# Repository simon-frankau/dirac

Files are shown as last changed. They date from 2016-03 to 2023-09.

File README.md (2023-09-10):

Dirac: The simplest single-board computer I can face building
=============================================================

Dirac is a simple single-board Z80-based retrocomputer. It's the
simplest one I can face building. I wanted to produce something that's
a bit nicer than a pure minimal computer, so it has:

 * Serial I/O
 * A counter/timer to provide the clock for serial I/O and also allow
   regular timer interrupts
 * Mass storage via SD card
 * Banked RAM

The banked RAM is a bit excessive, but it always seemed a bit magical
when I was small, and a 64KB address space is less than I really
like.

What's the aim?
---------------

The aim is to get CP/M running, with associated programs, with a
probably intermediate step of BASIC. The design is intended to be
retro where convenient. So, it has separate DIP chips for Z80, RAM,
EEPROM, CTC, SIO, and 74-series logic for the glue. I don't use a CPLD
let alone an FPGA or high-power modern microcontroller to cheat.

However, the non-volatile storage is EEPROM rather than EPROM, and I'm
just using a great big SRAM, rather than bothering with the pain of
DRAM. Serial I/O uses a proper Z80 SIO, but one ports connects to a
TTL serial to USB dongle, rather than RS-232 proper (the second port
does real RS232). After a false start, I use an oscillator package,
rather than a raw crystal. Mass storage is an SD card, via a break-out
board. I see little reason to cause myself a lot of pain of using a
more difficult and less available form of storage!

(Having said that, recreating old-school floppy drive control sounds
like a fun project in itself...)

Why's it called Dirac?
----------------------

Projects need names. "Z80-based single board computer" just isn't a
snappy name, and doesn't distinguishing it from any other.

I grew up on a ZX Spectrum. It had colour graphics. This machine has
no graphics at all. It has serial I/O, and that's basically
it. Instead of a spectrum of I/O, it's got a Dirac delta function.

(Random fact: Dirac was a fellow of my old College, and his gown still
hangs in the Master's Lodge. I believe it's chained in place, pesky
undergrads.)

Why's it taken so long?
-----------------------

(I bought my first pile of components in early 2010.)

Children. They're lovely, but they don't mix well with soldering irons!

What's here?
------------

* **[schematics](./schematics/README.md)** covers the hardware
* **[src](./src)** contains the assembly source to program it with
* **[tools](./tools)** contains the tools to do the required
    translations to make workable images

What's the current state?
-------------------------

I tried creating a simple loader. It allows you to encode your
binaries as hex, load them and execute them. With a recent fix, this
is now working reasonably reliably. I can plug the thing in to USB,
it'll power itself from the USB port, and I can talk to the monitor at
4800 8-N-1.

I have code to use the SD card interface in read-only mode, and have a
basic CP/M port running.

It will run Infocom's Hitchhiker's Guide To The Galaxy.

Where did the CP/M parts come from?
-----------------------------------

src/cpm22.asm is a lightly-modified copy of CPM22.Z80, extracted from
http://www.cpm.z80.de/download/cpm2-asm.zip

(I had disassembled a working CP/M image myself, but this comes with
comments and produces the same results so... why not?)

I previously used images/appleiicpm.dsk, which is taken from
http://schorn.ch/cpm/zip/cpm2.zip, as a relatively arbitrary
easy-to-reverse-engineer disk image. I've switched to building my own
disk images.

What do I need?
---------------

* **Kicad** for the schematics
* **zasm** (http://sourceforge.net/projects/zasm/ /
    http://k1.spdns.de/Develop/Projects/zasm/) for the assembly
* **lua** to run the tools

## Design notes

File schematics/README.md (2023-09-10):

Dirac's Hardware
================

[Schematics](./z80-schematics.pdf)

The schematics in this directory are in Kicad format. I previously
used Eagle, but it seems a good idea to support Open Source. I'm
clearly still learning it, so please forgive the worst
blunders. Feedback is appreciated.

Dirac's implemented using stripboard and a shedload of wires. You've
seen those neat stripboard projects? This is not one of
them. Super-tangled. This explains why you won't find any PCB designs.

Implementation is pretty straightforward, as I've implemented it a
feature at a time. An oscilloscope has been a life-saver, and I've
stuck pin-out labels on top of the chips, which has made working out
what's going on much easier.

Miscellaneous notes
-------------------

* NMI is basically unusable. It's not debounced, so by the time it's
  finished bouncing, the CPU's stack can be all over the place. The
  Spectrum had unusable NMI, so I feel I'm in good company. ;)

* The banking implementation is a bit funky, using as it does the
  74LS289. This is a chip obscure enough they don't even seem to have
  a CMOS version of. It's a small RAM, suitable for holding a banking
  map, but the outputs are inverting, meaning the physical address we
  think we're writing is actually the opposite of what we're really
  writing. We have to rearrange the EEPROM contents at the bank level
  when we write it. We also have to be careful with the TTL/CMOS
  levels between the chips. Fortunately, the big chips are
  TTL-tolerant, and I've used 74HCT for the others that are driven by
  the '289.

* We have a flip-flop to enable banking as the contents are in an
  unknown state at power on. All pages are mapped to bank 0 (physical
  page 0xFF) at start-up, and banking is enabled by the first write
  (and disabled on reset).

* Banking configuration can also be read back, which seemed a nice
  idea if you want to save and restore the current state, but does
  seem overkill really for such a simple design.

* Address decoding is such that you can page in RAM so that writes are
  disabled. Useful for faking ROM.

* There's a bog-standard Z80 CTC and SIO set-up. TO[01] are used to
  clock the SIO, and TO2 and TO3 are chained so that you can get a
  clock suited to a clock interrupt. The SIO output is TTL, so you can
  feed it into a USB serial adapter, or a level converter for
  traditional RS232. There are two ports, so in my implementation I
  have one of each.

* An SD card interface is implemented using the parallel ports.

Memory map
----------

The memory is divided into 4k (12-bit addressable) pages. The top
4-bits of Z80 "virtual" addresses are then mapped into "physical"
addresses in a 20-bit address space. That is, there's a 4-bit-to-8-bit
look-up.

Physical addressing is as follows:

$80000 - $9FFFF RAM, mapped read-only
$C0000 - $DFFFF RAM, mapped read-write

$00000 - $07FFF EEPROM

Yep, we only have 160KB of actual storage mapped into the 1MB address
space.

To perform virtual address mapping, so that address virtual address
$Xabc is mapped to $YZabc, you should "out" $YZ to I/O port $0X. You
can "in" from the same I/O port to get the current mapping.

Initially, banking is disabled, and all slots are mapped to $00xxx,
the bottom of the EEPROM. As soon as you write anything, banking is
enabled, and you will get random contents for the other banking slots.
So, your best bet is to initialise the bottom slot to $00xxx while
you're running code in it, and then initialise the other slots.

### Writing an EEPROM

The address lines that get passed through the banking hardware get
inverted before they actually reach the EEPROM, so you should write
your EEPROMs to cope with A12-A14 being inverted.

Parallel I/O ports and SD card
------------------------------

We have 8 bits of input and output available as a parallel port, at
$30. The bottom 3 bits of each port are used by the SD card SPI
interface:

### Out

$01 - Data
$02 - Clock
$04 - Select (active low)

### In

$01 - Data (inverted)
$02 - Card detected (active low)
$04 - Write protected (active low)

### Interface circuitry

The circuitry might look a little odd, so I'll explain. The SD card
uses 3.3V, and Dirac uses 5V, so we need some conversion. The SD card
has 100K pull-ups, and we use 10K resistors to convert, so we rather
take precedence.

In the outward direction, we need to bring the voltage down, so we use
voltage dividers. The ratio is 1:1, so the voltage is split in half.
2.5V when running off USB might seem a little low, but it should be
logic high for 3.3V logic, and won't go too high if Dirac is run off
e.g. 4x 1.5V AA batteries (giving 3V out, after division).

On the incoming direction, we just provide 5V pull-ups for card
detection and write protection lines (those being implemented as
switches pulling to ground on the SD card socket). The actual data
line is handled differently. 2.5V is TTL high, but not 5V CMOS high.
The input buffer is not HCT (I didn't look far enough ahead in Dirac's
design for that), but the inverter is. So, we pass it through the
inverter to buffer the level. Sadly this inverts the data line, but
that's easy enough to fix in software.

I/O map
-------

The upper nybble of the I/O port number denotes the I/O subsytem, the
lower nybble for addresses within the subsystem. The ports are:

$0X - Banking (see description above)
$1X - CTC
$2X - SIO
$3X - Parallel I/O ports

(And the rest are unassigned right now.)

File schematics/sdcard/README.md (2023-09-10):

# SD card breakout board schematics

[Schematic](./sdcard.pdf)

## What's this?

These are my reverse-engineered schematics for the SD card breakout
board I'm using. Why? While I'm not exactly an expert on SD card
breakout boards, I wouldn't be surprised if they're not all identical,
and the interpretation of the main board schematics (in the directory
above) rather relies on knowing how the breakout board is wired up and
how it connects to the actual SD card.

# So, what's the issue with the board?

While it has a 5V -> 3.3V regulator, it doesn't do any level
conversion on the signal lines, and SD cards aren't 5V tolerant. I
need to do some conversion on the Dirac side.

## And so?

I've added level conversion hardware to the main Dirac schematic to
handle this. The README.md in the directory above explains.

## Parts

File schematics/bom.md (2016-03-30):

Bill of materials
=================

NB: The part numbers on the schematic are often not *quite* right -
I'm using what's available in the parts library that is
pin-compatible. The actual choice of components is detailed below.

ICs
---

* U1 - Z84C0010PEG CMOS CPU (Z80) 10MHZ, 84C00, DIP40
* U2 - AS6C1008-55PCN SRAM, 1MB, 2.7V-5.5V, 128KX8, PDIP32
* U3 - CAT28C256BL-12 EEPROM, 256K, 32KX8, 120NS, PDIP28 (Use a ZIF socket)
* U4,5 - 2x 74LS289 16x4 inverting RAM with open collector output, DIP16
* U6 - 74HC138N 3-to-8 demux, DIP16
* U7 - 74HCT540N inverting octal buffer with tri-state outputs, DIP20
* U8 - 74HCT00N quad NAND, DIP14
* U9 - 74HCT32N quad OR, DIP14
* U10 - Z84C3006PEG CTC (Z80) 6MHZ, 84C30, DIP28
* U11 - Z84C4006PEG SIO/O (Z80) 6MHZ, 84C40, DIP40
* U12 - 74HC574E, oct D-type FF, DIP20
* U13 - 74HC541N, octal buffer with tri-state outputs, DIP20

Resistors
---------

* R1-8 - 10k resistor network
* R9-12 - 4x 10k, 0.25W 5% resistors

Capacitors
----------

* C1 - 10uF ceramic capacitor
* C2-15 - 13x 0.1uF ceramic capacitors (One per IC, plus reset-on-start)

Misc
----

* D1 - 5mm red LED
* SW1,2 - Normally-open push button
* X1 - Clock package, 2MHz
* JP1 - 2 pin 0.1" header and jumper
* P1 - 6 pin 0.1" female header

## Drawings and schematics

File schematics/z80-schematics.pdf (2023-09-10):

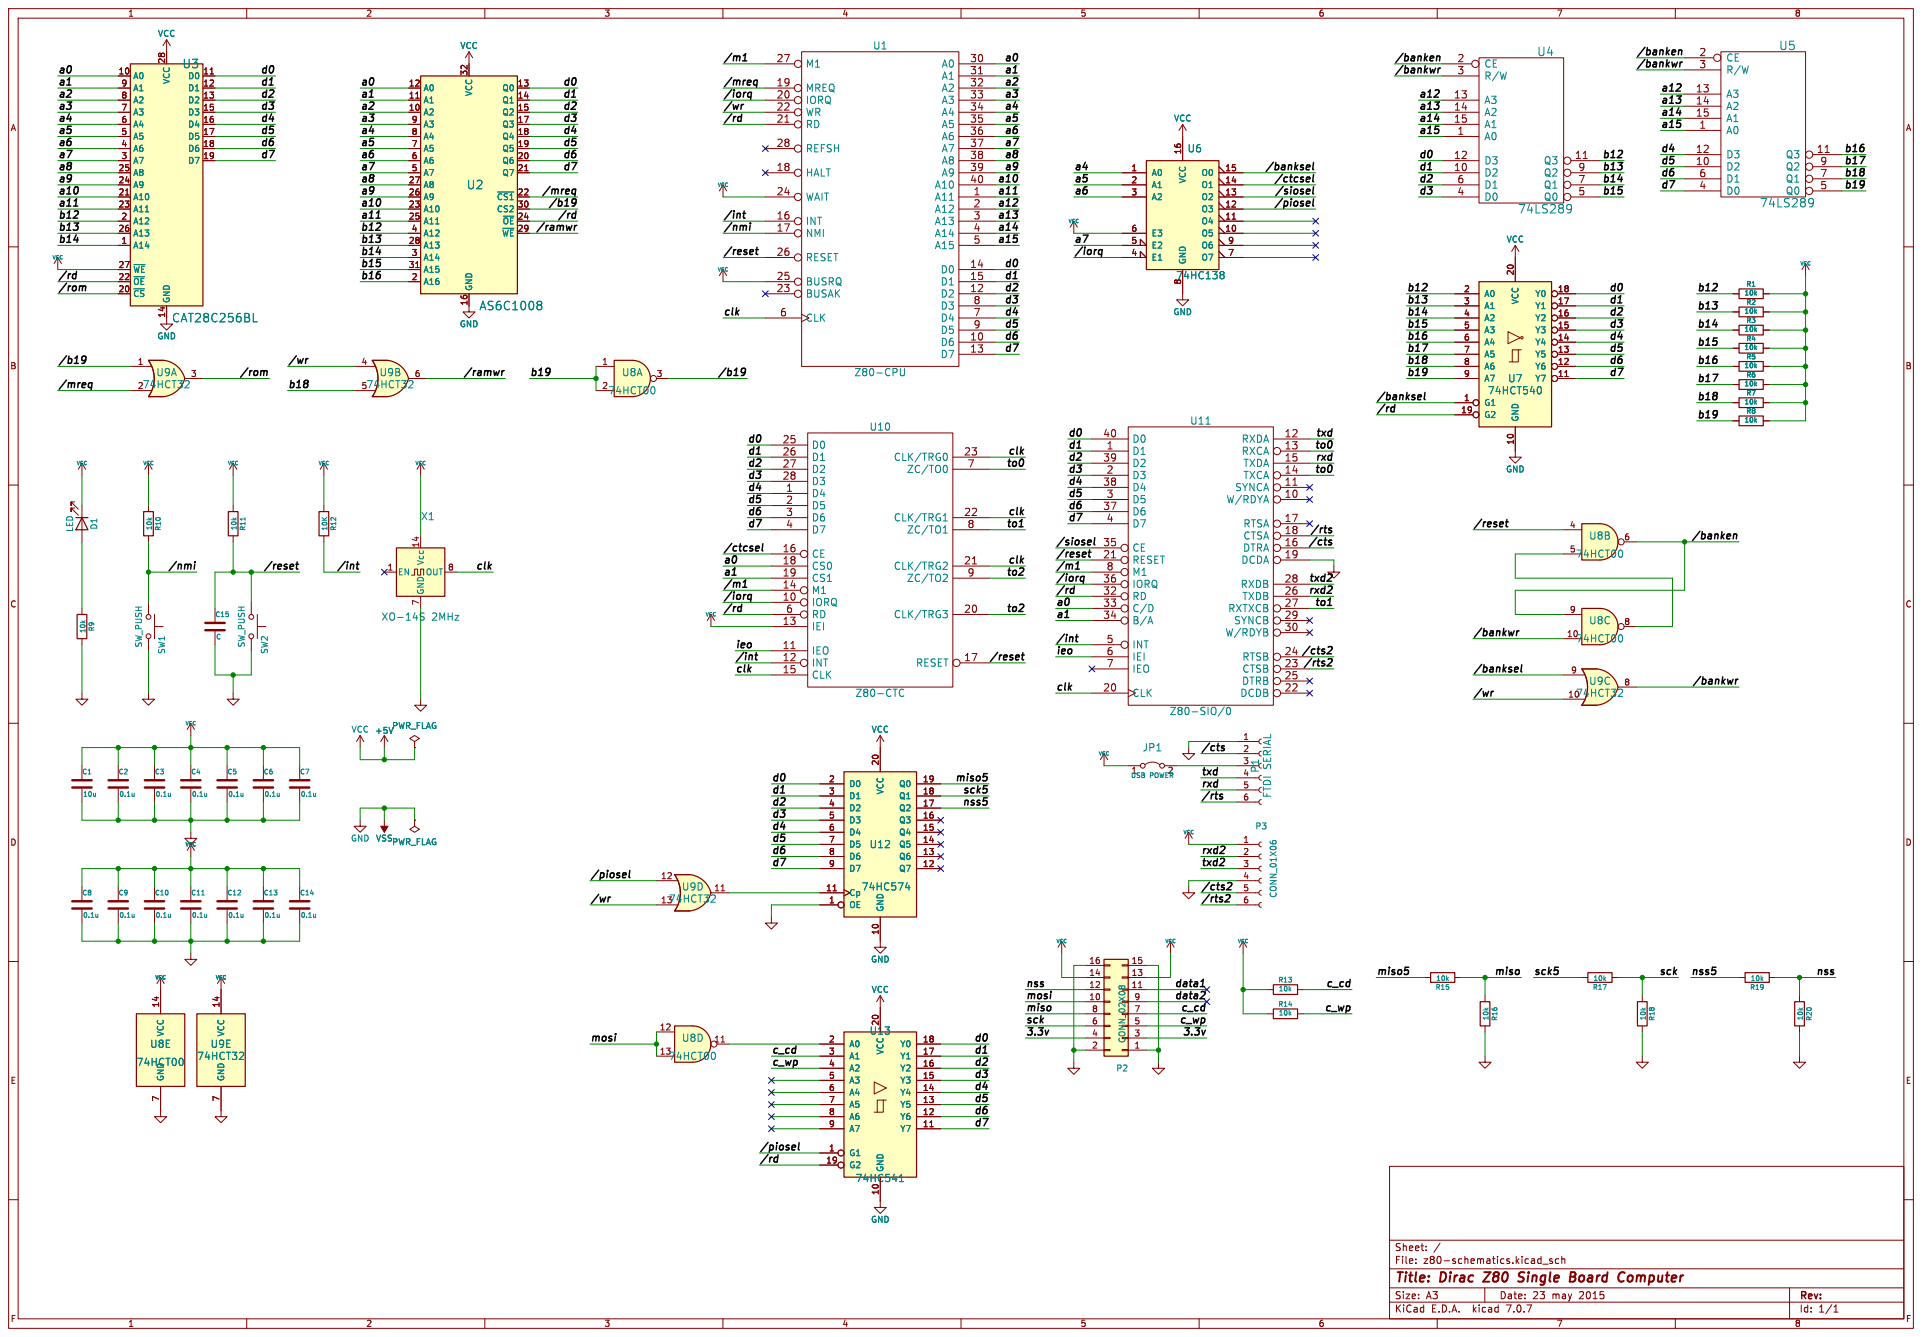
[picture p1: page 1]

Id: 1/1 Title: Dirac Z80 Single Board Computer File: z80-schematics.kicad_sch Sheet: /

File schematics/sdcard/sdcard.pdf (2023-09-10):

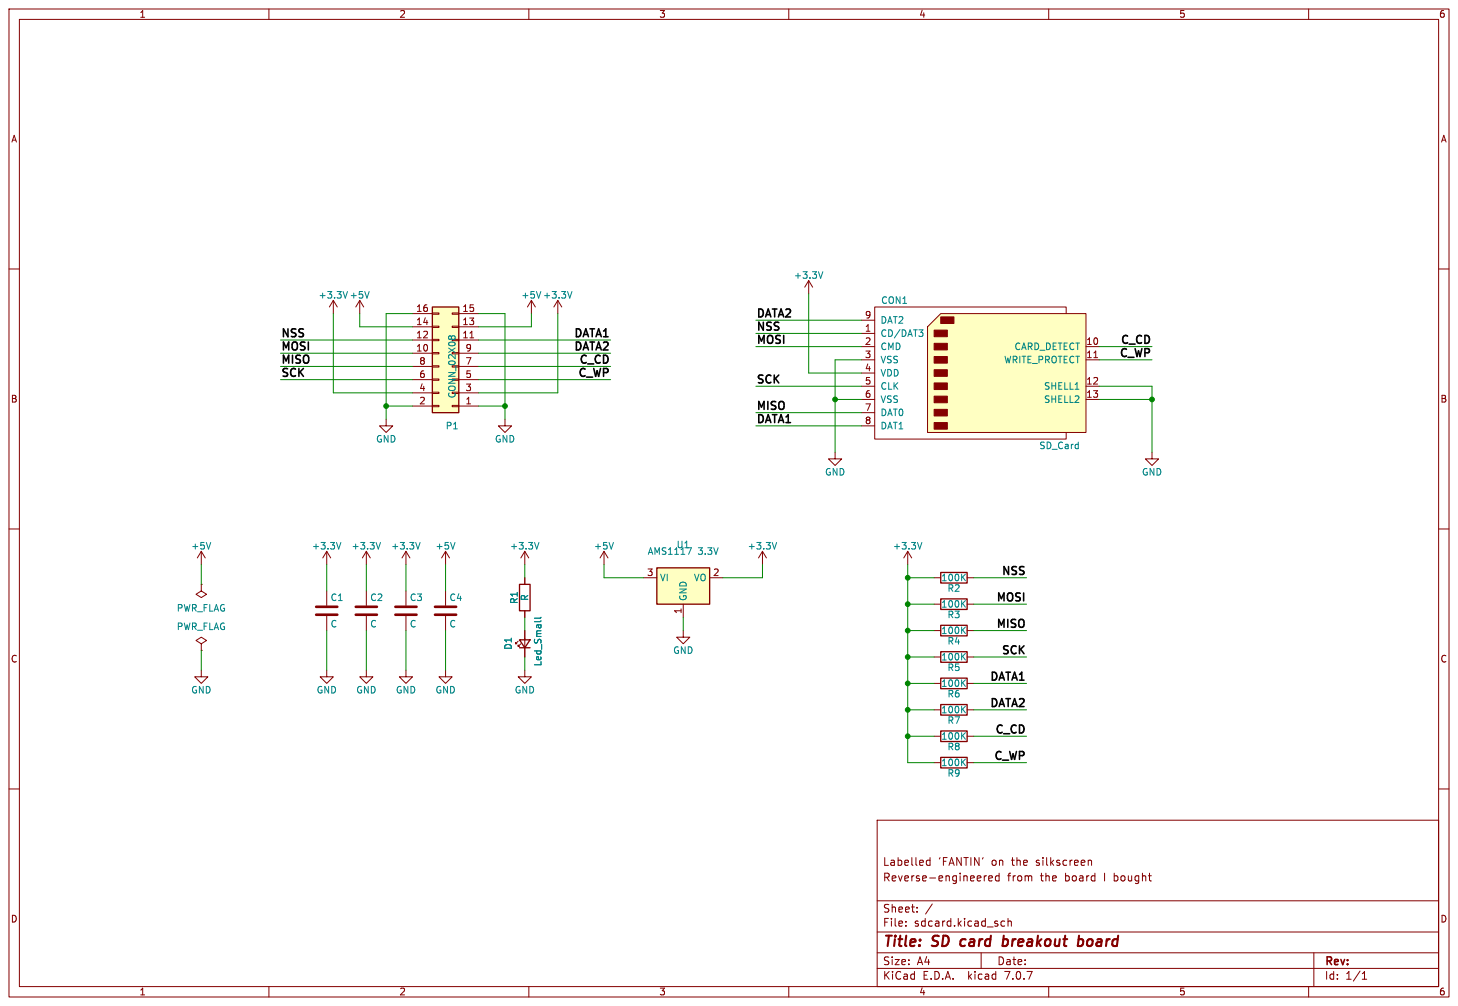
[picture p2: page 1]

1 VO 2 VI 3 U1 AMS1117 3.3V CD/DAT3 1 CARD_DETECT 10 WRITE_PROTECT 11 SHELL1 12 SHELL2 13 CMD 2 VSS 3 VDD 4 CLK 5 VSS 6 DAT0 7 DAT1 8 DAT2 9 CON1 SD_Card +5V
DATA2 C_CD

14 | 13
12 | 11

MOSI | | 10

Id: 1/1 Title: SD card breakout board

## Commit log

2013-10-06 Added a few quick comments on the slots used by the tests.
2013-11-14 Add exercising of the clock interrupt (needs debugging).
2013-11-15 Make the counter-interrupt-testing code work nicely.
2013-11-20 Prepare groundwork for testing SIO.
2013-11-23 Fix a couple of simple bugs in the SIO routines, added code to change case and echo back the character you typed. Simple non-interrupt serial I/O working.
2014-10-11 Very basic core schematic, in Kicad
    [z80-schematics.sch]
2014-10-11 Non-I/O digital logic complete - CPU, ROM, RAM, bank switching and glue
    [z80-schematics.sch]
2014-10-11 Update .gitignore with kicad file types
2014-10-11 Moving main buses over to label-based connections for improved readability
    [z80-schematics.sch]
2014-10-11 Tidied up the bank-switcher (changed to label-based connections)
    [z80-schematics.sch]
2014-10-11 Further label-ification
    [z80-schematics.sch]
2014-10-11 Finished switching to label-based connections
    [z80-schematics.sch]
2014-10-11 Added odds and ends to the schematic
    [z80-schematics.sch]
2014-10-19 Marked resistors as 10k
    [z80-schematics.sch]
2014-10-19 Added the CTC wiring
    [z80-schematics.sch]
2014-10-19 Added serial I/O
    [z80-schematics.sch]
2014-10-19 Added (incomplete) general I/O buffers.
    [z80-schematics.sch]
2014-10-19 Added decoupling caps.
    [z80-schematics.sch]
2014-10-22 Move assembly and tools into subdirectories
2015-01-06 Make case insensitive
2015-01-06 Add memory-map printing
2015-05-23 Added component identifiers to the schematic
    [z80-schematics.sch]
2015-05-23 Added initial (incomplete) bill of materials
2016-03-29 Update schematics to newer version of kicad
    [z80-schematics.sch]
2016-03-30 Label schematics with values
    [z80-schematics.sch]
2016-03-30 Add bill of materials for the schematic
2016-05-01 Fix accidental DRC failures
    [z80-schematics.sch]
2016-05-01 Fix DRC and fill in pull-ups on incomplete I/O circuitry
    [z80-schematics.sch]
2016-05-01 Add support for read-only RAM mapping
    [z80-schematics.sch]
2016-05-01 Update the README.md for the schematics
2016-05-01 Rename assembly source to the rather more conventional '.asm' suffix
2016-05-01 Added a status update for the current project status to README.md
2016-05-02 Enable use of CTC counter mode, to avoid pre-scale on serial clock
    [z80-schematics.sch]
2016-05-02 Update README.md with the current state of the project
2016-06-01 Enabled parallel I/O ports
    [z80-schematics.sch]
2016-06-01 Added schematic for the SD card breakout board
    [sdcard.kicad_pcb, sdcard.sch]
2016-06-03 Added schematics for SD card interfacing
    [z80-schematics.sch]
2016-06-05 Update READMEs with the current state of the SD card interface
2016-06-20 Cut more dead code from the bootloader
2016-06-20 Update README.md with current state of SD card work
2016-08-06 Slightly more consistent assembly formatting in the BIOS
2016-09-10 Add support for second serial port in the schematics
    [z80-schematics.sch]
2023-09-10 Update main schematic to newer Kicad, move non-ICs off rescue lib.
    [z80-schematics.kicad_sch, z80-schematics.sch]
2023-09-10 Switch other standard parts to standard library parts
    [z80-schematics.kicad_sch]
2023-09-10 Rename the rescue library to no longer be a rescue library.
    [z80-schematics.kicad_sch]
2023-09-10 Fix DRC error (missing power units on the updated 74xx chips).
    [z80-schematics.kicad_sch]
2023-09-10 Migrate sdcard project to new Kicad
    [sdcard.kicad_pcb, sdcard.kicad_sch]
2023-09-10 Tidy up switch of sdcard to new Kicad.
    [sdcard.sch]
2023-09-10 Add PDF schematic for sdcard
